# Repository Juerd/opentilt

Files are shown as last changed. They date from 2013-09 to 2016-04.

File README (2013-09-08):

No documentation yet. Stay tuned.

Requirements:
- Arduino Nano v3
- Arduino Uno bootloader (optiboot)
- MMA7361
- nRF24l01+
- RF24 fork at https://github.com/gcopeland/RF24
- AcceleroMMA7361 at https://code.google.com/p/mma7361-library/
- Entropy at http://code.google.com/p/avr-hardware-random-number-generation/

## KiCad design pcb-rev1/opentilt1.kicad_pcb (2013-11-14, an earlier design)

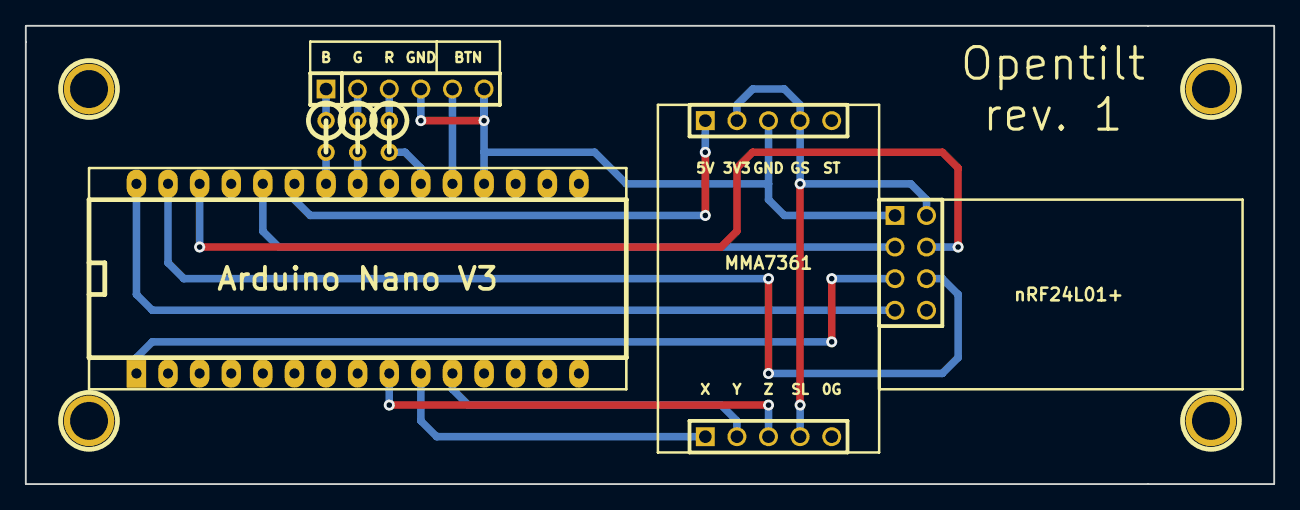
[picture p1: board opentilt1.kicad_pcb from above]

Board: 2 copper layers, 100.3 x 36.8 mm, 11 parts (0 on the bottom side), 5 nets.

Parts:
1PIN, 1PIN#2, 1PIN#3, 1PIN#4: P***; 1pin
B: R; R1
G: 150; R1
MMA7361: MMA1; PIN_ARRAY_5x1
P2: MMA2; PIN_ARRAY_5x1
P3: CONN_6; PIN_ARRAY-6X1
R: R; R1
nRF24L01+: CONN_4X2; pin_array_4x2

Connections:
GND: MMA7361.3, P3.4, P3.6, nRF24L01+.1
unnamed: P3.3, R.1
unnamed: B.1, P3.1
unnamed: G.1, P3.2
unnamed: MMA7361.2, MMA7361.4, P2.4, nRF24L01+.2

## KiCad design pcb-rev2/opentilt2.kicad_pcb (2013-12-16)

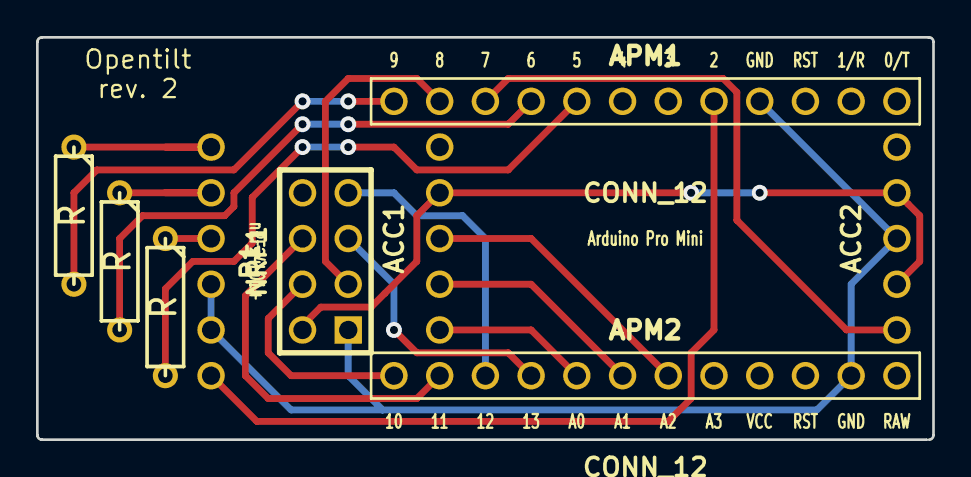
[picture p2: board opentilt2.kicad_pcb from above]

Board: 2 copper layers, 49.8 x 22.4 mm, 9 parts (0 on the bottom side), 18 nets.

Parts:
ACC1, ACC2: CONN_5; PIN_ARRAY_5x1_B
APM1, APM2: CONN_12; pin_array_12x1
NRF1: CONN_4X2; pin_array_4x2
P1: CONN_6; PIN_ARRAY-6X1_B
RB1: R; R3
RG1: R; R3
RR1: R; R3

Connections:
3V3: ACC1.4, ACC2.2, ACC2.4, NRF1.2
A0: ACC1.1, APM2.8
A1: ACC1.2, APM2.7
A2: ACC1.3, APM2.6
CLK: APM2.9, NRF1.5
D2: APM1.5, P1.6
D5: APM1.8, RR1.2
D6: APM1.9, RG1.2
D7: ACC2.1, APM1.10
D8: APM1.11, NRF1.3
D9: APM1.12, RB1.2
D10: APM2.12, NRF1.4
GND: ACC2.3, APM1.4, APM2.2, NRF1.1, P1.4, P1.5
MISO: APM2.10, NRF1.7
MOSI: APM2.11, NRF1.6
unnamed: P1.3, RR1.1
unnamed: P1.1, RB1.1
unnamed: P1.2, RG1.1

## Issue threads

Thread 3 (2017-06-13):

PCB Revision 2 assembly

olymk2, 2017-06-13:
I have started building your opentilt platform, and got some v2 pcb's fabricated, I notice your instructions only show version one.

Any chance of adding a pic of version 2 assembled, I have started to put it together but something does not feel right.

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

Can you confirm that the arduino should be oriented in this direction and same for the radio module.

if you could supply or update gh-pages with an image of version 2 that would be great.

Juerd, 2017-06-13:
Oliver Marks skribis 2017-06-13 14:19 (-0700):
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

Sorry, I've had other priorities and version 2 remain undocumented...

> 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
> Can you confirm that the arduino should be oriented in this direction
> and same for the radio module.

The devices should be mounted on the side that has the silkscreen
outline around the pins.

More importantly, it's designed for the Arduino Pro Mini, which is
smaller and does not have a USB port.

olymk2, 2017-06-13:
ah maybe thats where i am going wrong mine are arduino nano's I followed the silk screen but the arduino did not seem to fit, I may be able to float the nano as the pin arrangement looks the same as the mini it just has a few more.

I have 10 pcbs so perhaps i will try one with the nano and see if it works.

Thanks for the quick response and i can appreciate that you have not had time.

olymk2, 2017-06-16:
I have the mini's now, do you have any recommendation on how to power the mini's now they dont have usb ? just asking in case you already have a neat solution ?

Juerd, 2017-06-16:
Oliver Marks skribis 2017-06-15 23:30 (-0700):
> I have the mini's now, do you have any recommendation on how to power
> the mini's now they dont have usb ? just asking in case you already
> have a neat solution ?

I just soldered 2 dupont wires to a powerbank just like the one from
revision 1, and led them through a drilled hole in the side of the
powerbank. No more external wires!
--
Met vriendelijke groet, // Kind regards, // Korajn salutojn,

Juerd Waalboer  <juerd@tnx.nl>
TNX

olymk2, 2017-06-17:
cool, got one built now moved from hardware to software issues.

do you have links to  the libraries you used ?
```

/home/oly/repos/opentilt/opentilt.ino: In function 'void setup()':
opentilt:278: error: 'class EntropyClass' has no member named 'Initialize'
     Entropy.Initialize();

```

Triedd downloading but obviously there are different versions so I may have different ones than what you used when you wrote the code.

olymk2, 2017-06-18:
getting there now, code is sorted and uploaded, just need a few more components namely switch better leds and the batterys.

thanks for your help you may get a pr in the future with some tweaks :)

olymk2, 2017-06-29:
Got a couple of these built now but they are all flashing red 3 times, indicating there is an issue with the radio I have these which are the ones listed on your site i believe.

http://www.ebay.co.uk/itm/NRF24L01-Module-Transceiver-2-4Ghz-RF-Arduino-PI-ARM-Wireless-PACKS-x1-x2-x5/172269443013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

Any suggestions, guessing you may have hit this as you have an error code for it, anything i should check before i enter a major debug session ?

Juerd, 2017-06-29:
Oliver Marks skribis 2017-06-29 11:32 (-0700):
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

Those are the right ones.

> Any suggestions, guessing you may have hit this as you have an error
> code for it, anything i should check before i enter a major debug
> session ?

First thing to check is whether they get 3v3.
--
Met vriendelijke groet, // Kind regards, // Korajn salutojn,

Juerd Waalboer  <juerd@tnx.nl>
TNX

olymk2, 2017-06-30:
You may be correct on the power, I will do some more testing I have one that actually works.

Seems perhaps laptop usb and even the freshly charged battery's may not be quite good enough, but not all of them worked so i will re check the solder on the dud ones when i get a chance.

cheers will let you know the outcome

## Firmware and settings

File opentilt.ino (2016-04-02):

//#define DEBUG

#include <avr/wdt.h>
#include <avr/sleep.h>
#include <AcceleroMMA7361.h>
#include <SPI.h>
#include <nRF24L01.h>
#include <RF24.h>
#include <TimedButton.h>
#include <Entropy.h>
#include "color.h"
#include "shiv.h"
#include "debug.h"
#include "opentilt.h"

#define HW_REV2  // Hardware revision
#define CA_LED


// XXX master should send its value to the slaves

const float     shock_dead      =    4;

// To start the game
const float     shock_shake     =   20;
const int       shakes_start    =    5;
const int       time_shake      =  100;
const int       time_shock      =  300;
const int       timeout_shake   =  500;
const float     vertical_shock  =   25;

const int       max_players     =   32;  // 4 bytes of SRAM per player!
const int       max_teams       =    3;  // 4 bytes of SRAM per team!

const int       long_press_on   =  300;
const int       long_press_off  = 1000;
const int       timeout         = 1000;
const int       time_start      = 4000;

const int       broadcast_repeat =  15;
const int       broadcast_delay =    0;
const int       unicast_tries   =   15;
const int       unicast_delay   =    0;

const int       delay_main_loop =    2;

const int       time_heartbeat_master   = 1000;
const int       time_heartbeat_min      =  400;
const int       time_heartbeat_max      =  800;
const int       time_master_gone        = 4500;
const int       time_client_gone        = 6 * time_heartbeat_max + 100;
const int       time_error_delay        = 1000;

const Color     color_setup1 = gray50;
const Color     color_setup2 = white;
const Color     color_setup3 = orange;
const Color     color_master = cyan;
const Blink     blink_invite = { 500, 500 };
const Color     color_error  = red;
const Blink     blink_error  = { 300, 200 };
const Color     color_hello  = black;
const Color     color_player[max_teams] = { blue, yellow, magenta };
const Blink     blink_paired = { 1000, 1000 };
const Blink     blink_start  = { 200, 200 };
const Color     color_dead   = firebrick;
const Color     color_lose   = color_dead;
const Blink     blink_lose   = { 200, 2000 };
const Color     color_win    = lightgreen;
const Blink     blink_win    = { 200, 200 };
const Color     color_single = white;  // single player mode

#ifdef HW_REV1
const int pin_button = 2;   // interrupt
const int pin_led_r  = 3;   // pwm
const int pin_led_g  = 5;   // pwm
const int pin_led_b  = 6;   // pwm
const int pin_power  = 7;   // powers 3.3V LDO for mma7361 and nrf24l01+
const int pin_rf_ce  = 8;
const int pin_rf_cs  = 10;  // mosi = 11, miso = 12, clk = 13
const int pin_acc_x  = A6;  // non-nano doesn't have A6+A7
const int pin_acc_y  = A7;
const int pin_acc_z  = A5;
#endif

#ifdef HW_REV2
const int pin_button = 2;   // interrupt
const int pin_led_r  = 5;   // pwm
const int pin_led_g  = 6;   // pwm
const int pin_led_b  = 9;   // pwm
const int pin_power  = 7;   // powers 3.3V LDO for mma7361 and nrf24l01+
const int pin_rf_ce  = 8;
const int pin_rf_cs  = 10;  // mosi = 11, miso = 12, clk = 13
const int pin_acc_x  = A0;  // non-nano doesn't have A6+A7
const int pin_acc_y  = A1;
const int pin_acc_z  = A2;
#endif


const float shock_dead2 = shock_dead * shock_dead;
const float shock_shake2 = shock_shake * shock_shake;

static int time_heartbeat = time_heartbeat_max;
static int channel = 125;
static unsigned long master    = 0x69690000L;
static unsigned long broadcast = 0x96969696L;
static bool received = 0;
static Payload payload;
static Param param;  // for sending
static long int my_addr;
static unsigned int me;
static bool am_master = false;
static unsigned long prefix;
static signed long blinksync = 0;

static struct {
    AcceleroMMA7361 acc;
    float shock2;
    int dx, dy, dz, dt;
    unsigned int shakes;

    void init() {
        // Negative pin numbers are ignored by hacked library
        acc.begin(-1, -1, -1, -1, pin_acc_x, pin_acc_y, pin_acc_z);
        acc.setSensitivity(HIGH);

        update();
    }

    void update() {
        static int oldx = 0, oldy = 0, oldz = 0;
        static unsigned long oldt;
        int x = acc.getXAccel();
        int y = acc.getYAccel();
        int z = acc.getZAccel();
        unsigned long t = millis();

        dx = x - oldx, dy = y - oldy, dz = z - oldz, dt = t - oldt;
        oldx = x; oldy = y; oldz = z; oldt = t;

    }

    bool shock_3d(float threshold2) {
        float shock2 = (float) (dx*dx + dy*dy + dz*dz) / dt;
        return shock2 > threshold2;
    }

    bool vertical_shock(float threshold) {
        static unsigned long last_vertical_shock = 0;

        if (millis() - last_vertical_shock < time_shock) return false;

        float shock = (float) abs(dy) / dt;
        if (shock > threshold) {
            shakes = 0;
            last_vertical_shock = millis();
            return true;
        }
        return false;
    }

    bool shake() {
        static unsigned long last_shake = 0;

        if (shock_3d(shock_shake2) && last_shake < millis() - time_shake) {
            last_shake = millis();

            if (++shakes >= shakes_start) {
                shakes = 0;
                return true;
            }
        }

        if (last_shake < millis() - timeout_shake) shakes = 0;

        return false;
    }
} motion;

RF24            rf(pin_rf_ce, pin_rf_cs);
TimedButton     button(pin_button);

void led(Color color) {
    #ifdef CA_LED
        analogWrite(pin_led_r, 255 - color.r);
        analogWrite(pin_led_g, 255 - color.g);
        analogWrite(pin_led_b, 255 - color.b);
    #else
        // Common cathode. Assume lame LED with weak red.
        analogWrite(pin_led_r, color.r);
        analogWrite(pin_led_g, color.g >> 1);
        analogWrite(pin_led_b, color.b >> 1);
    #endif
}

void led_error(int blinks) {
    unsigned int once     = blink_error.on + blink_error.off,
                 total    = blinks * once - blink_error.off,
                 interval = total + time_error_delay;

    unsigned long now = millis() + blinksync;

    led(   now % interval < total
        && now % interval % once < blink_error.on
        ? color_error
        : off
    );
}

void led_blink(Blink pattern, Color c1, Color c2 = off) {
    unsigned long now = millis() + blinksync;
    unsigned int interval = pattern.on + pattern.off;
    led(now % interval < pattern.on ? c1 : c2);
}

void pin2_isr() {
    sleep_disable();
    detachInterrupt(0);
}

void power_down() {
    led(off);
    digitalWrite(pin_power, LOW);

    pinMode(pin_rf_ce, INPUT);
    digitalWrite(pin_rf_ce, LOW);
    pinMode(pin_rf_cs, INPUT);
    digitalWrite(pin_rf_cs, LOW);

    AGAIN:
    wdt_disable();
    sleep_enable();
    attachInterrupt(0, pin2_isr, LOW);
    set_sleep_mode(SLEEP_MODE_PWR_DOWN);
    ADCSRA = 0;  // disable ADC
    PRR = B10010111;
    cli(); sleep_bod_disable(); sei();
    sleep_cpu();
    sleep_disable();
//    ADCSRA |= (1<<ADEN);  // enable ADC
    delay(5);  // workaround: sometimes millis() is 0...
    unsigned long min_time = millis() + long_press_on;
    delay(10);  // for more reliable readings
    while (digitalRead(pin_button) == LOW && millis() < min_time);
    if (millis() < min_time) goto AGAIN;
    reset();
}

void reset() {
    wdt_enable(WDTO_30MS);
    while (42);
}

extern int __bss_end;
extern void *__brkval;

int get_free_memory() {
    int free_memory;
    if((int)__brkval == 0)
         free_memory = ((int)&free_memory) - ((int)&__bss_end);
    else free_memory = ((int)&free_memory) - ((int)__brkval);
    return free_memory;
}


void setup() {
    #ifdef DEBUG
        Serial.begin(115200);
        debug_begin();
    #endif
    pinMode(pin_power, OUTPUT);
    pinMode(pin_led_r, OUTPUT);
    pinMode(pin_led_g, OUTPUT);
    pinMode(pin_led_b, OUTPUT);
    led(color_setup1);

    digitalWrite(pin_power, HIGH);

    Entropy.Initialize();

    motion.init();

    rf.begin();
    rf.setChannel(channel);
    rf.setPayloadSize(sizeof(Payload));

    time_heartbeat = Entropy.random(time_heartbeat_min, time_heartbeat_max);

    // POST
    if (! rf.isPVariant()) {
        D("No nRF24L01+ detected.");
        digitalWrite(pin_power, LOW);
        for (;;) led_error(error_no_radio);
    }
}


enum state_enum {
    CLIENT_COMM_ERROR,
    CLIENT_HELLO, CLIENT_CONFIG, CLIENT_PAIRED,
    MASTER_SETUP, MASTER_INVITE, MASTER_GAME_SETUP,
    GAME_START, GAME, GAME_OVER
} state = CLIENT_HELLO;

int oldstate = -1;


bool send(unsigned long destination, uint8_t msg, union Param param) {
    int i;
    bool ok, is_broadcast = (destination == broadcast);
    static Payload p;

    p.seq++;
    p.msg = msg;
    p.param = param;
    D("SEND to=%08lx seq=%d msg=%d", destination, p.seq, p.msg);
    rf.openWritingPipe(destination);
    rf.stopListening();

    if (msg == msg_heartbeat) p.param.heartbeat.time = millis();
    ok = rf.write(&p, sizeof(p), is_broadcast);
    if (is_broadcast) {
        for (i = 1; i < broadcast_repeat; i++) {
            delay(broadcast_delay);
            if (msg == msg_heartbeat) p.param.heartbeat.time = millis();
            rf.write(&p, sizeof(p), is_broadcast);
        }
    }

    if (!is_broadcast) rf.openReadingPipe(0, broadcast);
    rf.startListening();

    zero(param);
    return ok;
}


bool master_loop() {
    static int num_players = 1;
    static unsigned long wait_until = 0;
    static unsigned long alive[ max_players ];
    static unsigned long next_heartbeat = millis() + time_heartbeat;
    static int teams = 1;
    int i;

    if (millis() > next_heartbeat) {
        send(broadcast, msg_heartbeat, param);
        next_heartbeat = millis() + time_heartbeat;
    }

    switch (state) {
        case CLIENT_COMM_ERROR:
        case CLIENT_HELLO:
        case CLIENT_CONFIG:
        case CLIENT_PAIRED:
            break;

        case MASTER_SETUP: {
            led(color_master);
            prefix = 0x96000000L + (Entropy.random(0xFFFF) << 8);
            broadcast = prefix + 0xff;
            time_heartbeat = time_heartbeat_master;

            rf.openReadingPipe(0, broadcast);
            rf.openReadingPipe(1, master);
            rf.startListening();

            D("I am master! prefix=%08lx free=%d", prefix, get_free_memory());

            wait_until = 0;

            state = MASTER_INVITE;

            break;
        }
        case MASTER_INVITE: {
            if (received && payload.msg == msg_hello) {
                delay(10);
                param.config.id    = num_players;
                int team = num_players % teams;
                param.config.color = color_player[ teams - team - 1 ];
                param.config.prefix = prefix;
                send(
                    master + payload.param.hello.id,
                    msg_config,
                    param
                );
                num_players++;
                led(color_hello);
                wait_until = millis() + 500;
            }

            if (millis() >= wait_until) {
                led_blink(blink_paired, color_player[teams - 1], color_master);
            }

            if (motion.vertical_shock(vertical_shock)) {
                if (num_players > teams || (teams == max_teams && num_players > 1)) {
                    led(color_error);
                    wait_until = millis() + 1000;
                    break;
                }
                teams++;
                if (teams > max_teams) teams = 1;

                led(color_player[teams - 1]);
                wait_until = millis() + 1000;
                break;
            }

            if (motion.shake()) {
                state = MASTER_GAME_SETUP;

                param.config.id = 0;
                param.config.color =
                    num_players == 1
                    ? color_single
                    : color_player[ teams - 1 ];
                payload.msg = msg_config;
                payload.param = param;
                return true;
            }

            break;
        }
        case MASTER_GAME_SETUP: {
            master = prefix + 0x00;
            rf.openReadingPipe(1, master);
            rf.startListening();

            param.start_game.time = time_start;
            send(
                broadcast,
                msg_start_game,
                param
            );

            for (i = 0; i < num_players; i++)
                alive[i] = millis() + time_start + time_heartbeat_max;

            payload.msg = msg_start_game;
            payload.param = param;
            state = CLIENT_PAIRED;
            return true;
        }
        case GAME:
        case GAME_START: {
            if (motion.shake()) {
                state = MASTER_GAME_SETUP;
                break;
            }

            if (received && payload.msg == msg_status) {
                int id = payload.param.status.id;
                if (payload.param.status.alive) {
                    if (alive[id]) {
                        alive[ payload.param.status.id ] = millis();
                    } else {
                        // In case you hadn't noticed, you were already dead.
                        // (e.g. communication timeout)
                        D("%d says they're alive. They're not.", id);
                        send(prefix + id, msg_you_die, param);
                    }
                } else {
                    alive[ id ] = 0;
                }
            }

            if (num_players < 2) break;  // No winners in single player :)

            unsigned char num_alive = 0;
            unsigned char num_alive_per_team[ max_teams ];
            memset(num_alive_per_team, 0, sizeof(num_alive_per_team));
            unsigned char survivor;
            unsigned char surviving_team;
            for (i = 0; i < num_players; i++) {
                if (i ? (alive[i] > millis() - time_client_gone) : alive[i]) {
                    num_alive++;
                    num_alive_per_team[ i % teams ]++;
                    survivor = i;
                    surviving_team = i % teams;
                } else if (alive[i]) {
                    D("%d timed out: seen=%d uptime=%d", alive[i], millis());
                    alive[i] = 0;
                }
            }

            if (teams == 1 && num_alive == 1) {
                if (survivor == 0) {  // that's me!
                    send(broadcast, msg_game_over, param);
                    payload.msg = msg_game_over_you_win;
                    return true;  // client_loop will set state = G_O_SETUP.
                } else {
                    send(prefix + survivor, msg_game_over_you_win, param);
                    send(broadcast, msg_game_over, param);
                    state = GAME_OVER;
                }
            } else if (teams > 1) {
                int num_teams_alive = 0;
                for (i = 0; i < teams; i++) {
                    if (num_alive_per_team[i]) num_teams_alive++;
                    D("team %d alive %d", i, num_alive_per_team[i]);
                }

                if (num_teams_alive == 1) {
                    for (i = surviving_team; i < num_players; i += teams) {
                        send(prefix + i, msg_game_over_you_win, param);
                    }
                    send(broadcast, msg_game_over, param);

                    // Hack: just send these again in case some were not rcvd.
                    for (i = surviving_team; i < num_players; i += teams) {
                        send(prefix + i, msg_game_over_you_win, param);
                    }

                    if (surviving_team == 0) {  // includes me!
                        payload.msg = msg_game_over_you_win;
                        return true;
                    }
                    state = GAME_OVER;
                }
            }


            break;
        }
        case GAME_OVER: {
            if (motion.shake()) {
                state = MASTER_GAME_SETUP;
            }

            break;
        }
    }

    return false;
}
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
void loop() {
    static int previous_broadcast = -1;

    if (state != oldstate) {
        D("State changed from %d to %d.", oldstate, state);
        oldstate = state;
    }
    if (button.down(long_press_off)) {
        led(off);  // visual feedback
        while (button.down());
        delay(1000);  // XXX debounce
        power_down();
    }

    motion.update();

    // If received is already 1, it's because we're master and sending a
    // message to ourselves :)
    while (!received && rf.available()) {
        zero(payload);
        rf.read(&payload, sizeof(payload));
        received = 1;
        if (payload.msg < 100) {
            // broadcasts; skip duplicates
            if (payload.seq == previous_broadcast) received = 0;
            previous_broadcast = payload.seq;
        }
        if (received) D("RECEIVED: seq=%d msg=%d", payload.seq, payload.msg);
    }


    if (!received) {
        received = client_loop();
    } else if (payload.msg < 100 || payload.msg >= 200) {
        // don't overwrite 'received' if mesage is for master.
        received = client_loop();
    }

    if (am_master) received = master_loop();
    else received = 0;

    delay(delay_main_loop);
}

// vim: ft=cpp

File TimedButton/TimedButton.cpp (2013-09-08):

#include "TimedButton.h"
#include <inttypes.h>
#include "Arduino.h"

TimedButton::TimedButton(uint8_t pin) {
    pinMode(pin, INPUT);
    digitalWrite(pin, HIGH);
    _pin = pin;
    _begin_time = 0;
}

/* Button was pressed for min_time ms, then released. */
uint8_t TimedButton::pressed(unsigned long min_time) {
    if (_begin_time) {
        unsigned long elapsed = millis() - _begin_time;
        if (elapsed < DEBOUNCE_TIME) return false;
        if (digitalRead(_pin) == LOW) return false;
        _begin_time = 0;
        if (elapsed >= min_time) return true;
        return false;
    }
    if (digitalRead(_pin) != LOW) return false;
    _begin_time = millis();
    return false;
}

/* Button was pressed for min_time ms, possibly still being pressed.
   Needs repeated calls to pressed() or down() to reset state afterwards.
*/
uint8_t TimedButton::down(unsigned long min_time) {
    int pressed = !digitalRead(_pin);
    if (! pressed) {
        _begin_time = 0;
        return false;
    }

    if (! min_time) return true;
    else if (! _begin_time) _begin_time = millis();

    unsigned long elapsed = millis() - _begin_time;
    return elapsed >= min_time;
}

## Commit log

2013-09-08 Power up with long press
2013-09-08 Playable game.
    Broadcast still fails sometimes.
    [opentilt1.ino]
2013-09-12 Things work now.
    Addresses apparently shouldn't have too many FF's or 00's, so 0xFFFFFFFFL had a
    high chance of not receiving packets.
    Also, there's some time synching stuff now, but it doesn't work too well because
    the arduino clock isn't very accurate :-)
    [opentilt1.ino]
2013-09-12 Mostly reliability changes.
    Sync blinking on state change, no more uptimes in protocol.
    Add random delay on init to fix most startup race conditions during development.Change init colors.
    [opentilt1.ino]
2013-09-12 Client-to-master heartbeat + single player mode + bugfix
    Bugfix: broadcast address was reset to 0.
    [opentilt1.ino]
2013-09-12 Randomized broadcast works again: forcing comm timeout no longer necessary
    [opentilt1.ino]
2013-09-13 Bugfix and ruggedizing :)
    Bugfix: client's alive variable would not be reset on game restart
    [opentilt1.ino]
2013-09-21 Shiv sleep_bod_disable because Arduino ships old avr tools.
2013-09-22 Upload to all arduinos with one command.
    Compile (without uploading) in Arduino IDE, then run perl multi_upload.pl
2013-09-22 Randomize heartbeats and retransmit faster, hoping this will avoid collisions.
    [opentilt1.ino]
2013-09-22 Separate comm debug (floods), fix "no you're dead", tweak heartbeat
    [opentilt1.ino]
2013-09-22 Let master deal with failed race condition by declaring a winner.
    [opentilt1.ino]
2013-09-22 Fix some compiler warnings
    [opentilt1.ino]
2013-09-27 Several big changes.
    - Moved non-config constants and struct definitions to .h file.
    - Don't skip to GAME_OVER state until master says so.
    - Refactored blinking and made blink patterns configurable.
    - Power-on-self-test for radio (lost 10 minutes over unnoticed disconnection).
    [opentilt1.ino]
2013-09-27 Synchronise blinking, for real this time.
    These arduino's don't exactly have a very stable clock source, but by syncing
    every master heartbeat, we can at least pretend they're all the same.
    Somehow, the synchronised blinking is kind of creepy...
2013-09-27 Blink slower.
    This way, small sync errors are less noticeable.
    [opentilt1.ino]
2013-11-14 Opentilt PCB Rev. 1
    [opentilt1.kicad_pcb, opentilt1.sch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]
2013-12-16 New PCB
    Based on Arduino Pro Mini (5V).
    [opentilt1.kicad_pcb, opentilt1.sch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]
2013-12-16 Add PCB rev 2 pinout, fix "power down".
    The line to disable the ADC didn't appear to actually do anything.
    Approx. 60 µA would flow out of the CE and CS pins.
    After removing the power-on LED and the LDO from the Arduino Pro Mini,
    fixing the ADC, and setting some output pins to tristate (input), the
    remaining current measured 150 nA, which is well below the autodischarge
    rate of any typical battery and negligible compared to the consumption
    of protection and charger circuits.
    [opentilt.ino]
2013-12-16 Fix typo; accept shorter power-button press.
    [opentilt.ino]
2013-12-22 Change power button timings, implement auto-off for clients, fix sensitivity
    [opentilt.ino]
2013-12-24 Disable accelerometer and radio on auto power down
2014-04-13 Compensate for meh LED
2016-04-02 CA led
